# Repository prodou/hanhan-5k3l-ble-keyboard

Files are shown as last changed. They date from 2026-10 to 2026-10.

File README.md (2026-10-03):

# HanHan 5K3L — ESP32-C3 蓝牙五键三灯 + HanHan Agent

## 项目组成

- `firmware/esp32c3_5btn_3led_ble/` — ESP32-C3 固件(Arduino + NimBLE-Arduino)
  - 5 个按键(GPIO0/1/3/4/10)→ BLE HID 键盘, 发送 F13~F17
  - 3 个 LED(GPIO2/6/7, 共用一颗限流电阻)→ 独立的自定义 BLE GATT 特征值控制,
    支持常亮/闪烁/流水灯几种效果模式(见下方"LED 效果协议"), 硬件层固定
    10ms 一帧的分时复用, 三颗灯各自分到一段首尾相接、互不重叠的专属导通窗口,
    **任意时刻最多只有一颗 LED 导通**, 避免共用限流电阻叠加电流; 每颗灯的窗口
    宽度(= 相对亮度)可以自由分配, 只要三者总和不超过 100%(固件会自动按比例
    缩小超出的部分)
  - 启用 BLE 绑定(bonding), 支持断开自动重连; 同时支持**两条并发 BLE 连接**
    (例如手机/电脑当 HID 键盘用的同时, HanHan Agent 再单独连一条做 LED 控制),
    并带有广播看门狗兜底, 避免意外情况下"怎么都搜不到设备"
  - **同时长按 GPIO0 + GPIO1 五秒** → 断开当前连接并清空所有绑定记录, 方便换设备配对
- `HanHanAgent/` — macOS 菜单栏小工具(Swift)
  - 全局拦截来自本设备的 F13~F17 按键(不会传到当前聚焦的窗口)
  - 背景转发(不切换焦点)到用户在菜单里选定的目标 App(固定某个实例, 或"跟随前台窗口"全局模式)
  - 菜单里的"LED 控制..."打开一个独立窗口, 合并了效果预设(全灭/常亮/闪烁/流水灯等)
    和亮度/分配滑块(三个拖动条, 总和 100 以内自由分配), 自动持久化到本地
    并在每次重连时自动下发给固件
- `tools/led_test.py` — 独立的 LED 效果测试脚本(需要 `pip install bleak`,
  且运行环境要有正常的图形登录会话以便弹出蓝牙权限提示)

## LED 效果协议

自定义 Service UUID: `6E400100-...`, 下属两个 Characteristic:

### 效果特征值 `6E400101-...`(mask + mode, 2 字节)

| byte0 (mask) | byte1 (mode) | 效果 |
|---|---|---|
| bit0/1/2 = LED0/1/2 是否参与 | 0 | 全灭(忽略 mask) |
| | 1 | 常亮(mask 选中的灯常亮, `0b111` = 三灯都亮) |
| | 2 | 闪烁(mask 选中的灯一起慢闪: 亮400ms/灭400ms) |
| | 3 | 流水灯(忽略 mask, LED0→LED1→LED2 依次点亮, 每步150ms) |

只写 1 个字节时视为旧协议, 自动当作 `mode=1`(常亮)处理。

### 亮度/分配特征值 `6E400102-...`(3 字节, 可写可读)

`byte[i]` = LED`i` 分配到的"帧内占比"百分比(0~100), **三者总和不能超过 100**
(固件和 HanHan Agent 都会在超出时按比例整体缩小)。时分复用保证任意时刻
最多一颗 LED 导通, 所以无论怎么分配都不会叠加电流, 可以放心按喜好调整:
想让某颗更亮就多分配一些给它, 或者单独调低偏亮的那颗颜色来找平衡。
默认各 30(总和 90)。HanHan Agent 会把每次调整后的值持久化并在每次重连成功后
自动重新下发一遍(固件重启后这个状态会丢失, 需要重新下发)。

> **⚠️ 踩坑记录**: 固件每次新增/修改 BLE 特征值(Characteristic)后, macOS 可能会
> 沿用之前连接缓存的旧 GATT 服务列表, 导致 App 发现不到新加的特征值(表现为:
> App 显示"已连接", 但写入新特征值毫无效果)。解决方法: 系统设置 -> 蓝牙 里把
> "HanHan 5K3L v0.1" 这个设备**移除/忽略**掉, 完全退出并重新打开 HanHan Agent
> 让它重新扫描连接一次, 缓存就会刷新。以后固件 GATT 结构有变化时都建议先这么做一遍。

测试示例:

```bash
pip install bleak
python3 tools/led_test.py static 0b111   # 三灯都亮
python3 tools/led_test.py blink 0b011    # LED0/LED1 一起慢闪
python3 tools/led_test.py chase          # 流水灯
python3 tools/led_test.py off            # 全灭
```

## 固件编译/烧录

需要先安装 `arduino-cli`、ESP32 开发板支持包(`esp32:esp32`)、`NimBLE-Arduino` 库。

```bash
arduino-cli compile --fqbn esp32:esp32:esp32c3:CDCOnBoot=cdc \
  firmware/esp32c3_5btn_3led_ble --output-dir build_out

arduino-cli upload -p /dev/cu.usbmodemXXXX \
  --fqbn esp32:esp32:esp32c3:CDCOnBoot=cdc \
  -i build_out/esp32c3_5btn_3led_ble.ino.bin \
  firmware/esp32c3_5btn_3led_ble
```

烧录前需要先按住 BOOT、再按一下 RESET、再松开 BOOT 进入下载模式
(部分板子插上 USB 会自动进入, 视板子而定)。

## HanHan Agent 安装 / 使用

1. 到 [Releases](../../releases) 下载最新的 `HanHanAgent.zip`, 解压后得到 `HanHan Agent.app`。
2. 拖到 `~/Applications` 或 `/Applications`, 双击打开(首次因为是临时签名, 需要右键 →
   打开 → 确认允许运行)。
3. 打开后会在菜单栏出现 "HH" 图标。第一次运行会请求"辅助功能"权限 ——
   去 **系统设置 → 隐私与安全性 → 辅助功能**, 勾选 "HanHan Agent"
   (没有这个权限完全收不到按键)。
4. 点菜单栏 "HH" 图标, 下拉列表会显示当前运行中的 App, 选择你要接收按键的目标。
5. 按板子上的按键, F13~F17 会被拦截并"背景注入"到选定的目标 App, 不会影响你当前正在
   操作的窗口。

也可以自己从源码编译:

```bash
cd HanHanAgent
./build.sh
open "build/HanHan Agent.app"
```

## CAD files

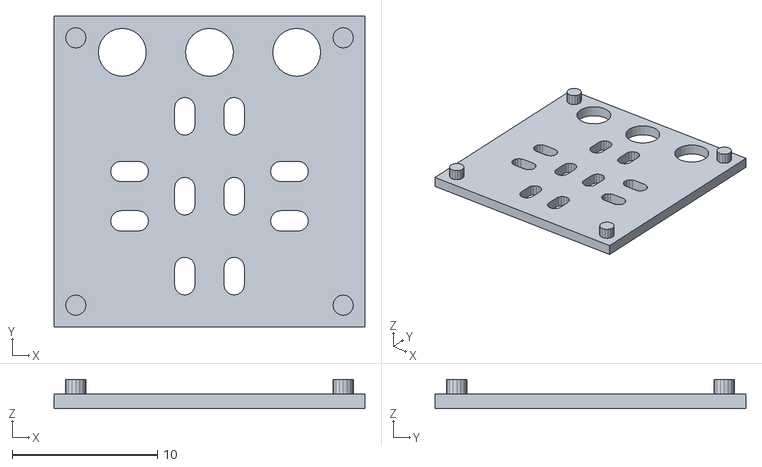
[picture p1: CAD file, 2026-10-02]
dpad_case/retainer.stl
21.4 x 21.4 x 2.00

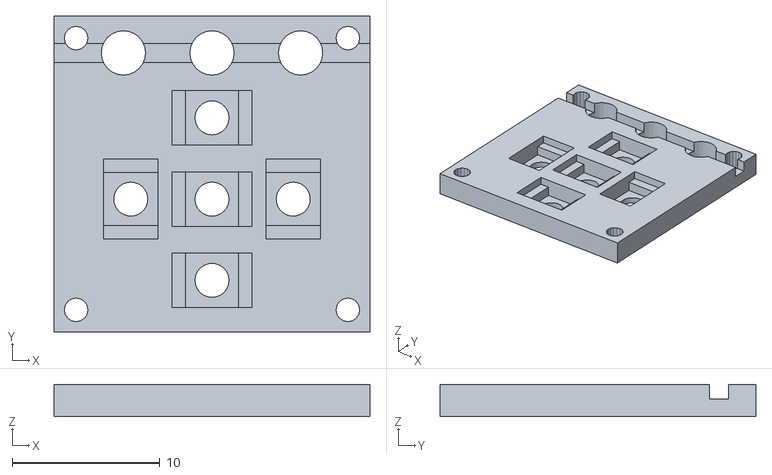
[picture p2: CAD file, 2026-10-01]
dpad_case/carrier.stl
21.4 x 21.4 x 2.20

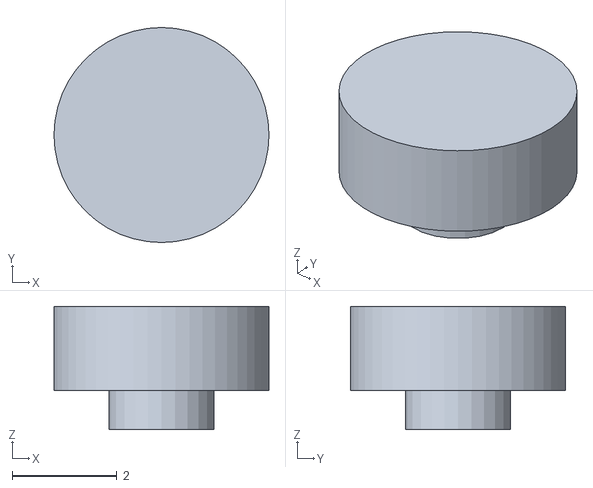
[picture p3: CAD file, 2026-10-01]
dpad_case/cap.stl
4.10 x 4.10 x 2.35

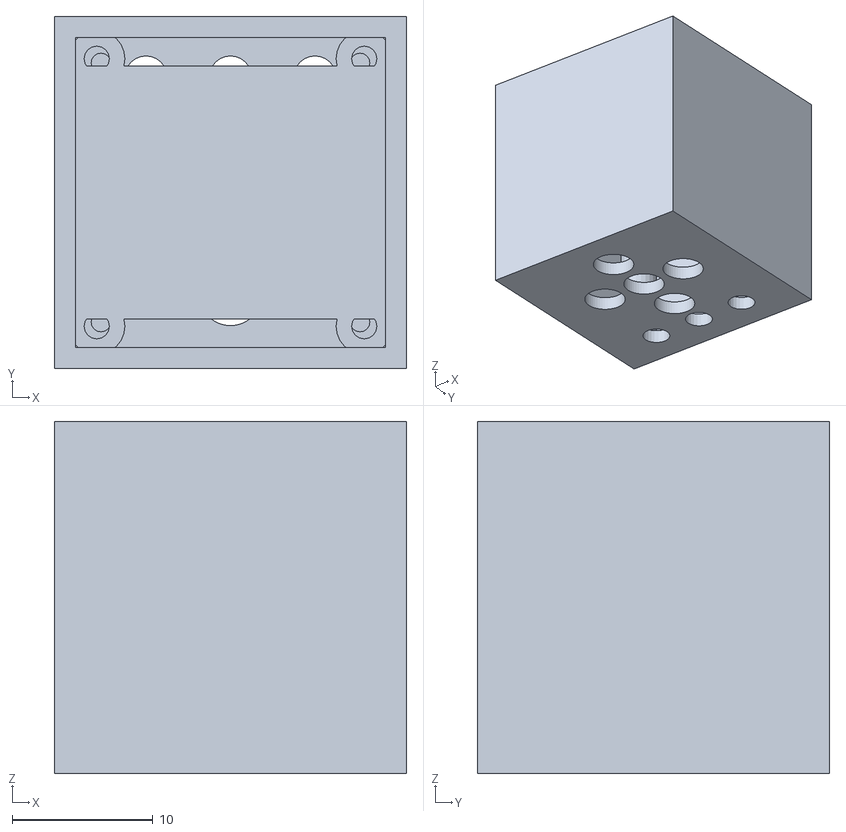
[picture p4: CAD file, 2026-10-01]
dpad_case/shell.stl
25.0 x 25.0 x 25.0

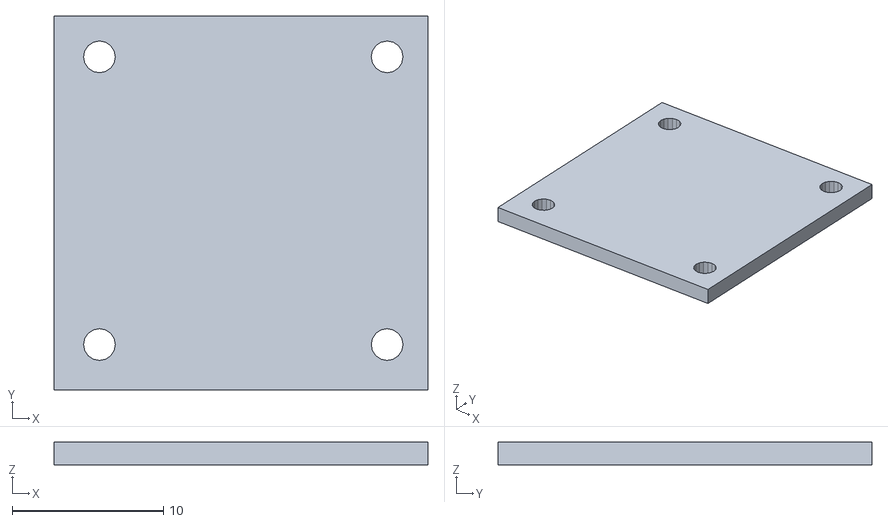
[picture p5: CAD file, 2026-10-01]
dpad_case/back.stl
24.7 x 24.7 x 1.50

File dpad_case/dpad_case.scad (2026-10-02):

// ============================================================
// HanHan 5K3L — 25mm立方体 外壳 + 载板 参数化设计 (v7: 简化卡槽为贯穿式, 走线全部挪到盖板)
// 对应 firmware/esp32c3_5btn_3led_ble
//   5键: GPIO0/1/3/4/10 (上下左右+中)
//   3灯: GPIO2/6/7 (共用限流电阻, 分时复用)
//
// v2改动: 十字按键放大占满22x22; 新增cap零件(面板大孔+小顶杆压实际按键); LED放到十字间隙里
// v3改动: LED改回一排放在面板顶部; cap/面板孔缩小, 露出LED光线; 十字整体下移腾出LED排空间
// v4改动: 根据实拍datasheet量到的真实贴片按键尺寸(3.3x3.4x1.5mm本体,
//   引脚左右伸出共4.0mm, 2mm按压圆点), 重做载板卡槽
// v5改动: 左右按键转90度(引脚变竖直), 同排三键从"引脚对引脚"变"本体对本体",
//   腾出空间加大焊接预留; 每按键独立卡槽+两个过线孔
// v6改动: 卡槽改成"台阶+深槽"结构试图解决引脚比本体低的问题, 新增盖板(retainer)
//   —— 打样后发现引脚两侧那两个深槽做得太大太夸张, 偏离了"中间凹一点放进去"的本意
// v7改动: 卡槽改成简单矩形直接贯穿整个载板厚度 —— 打样后发现贯穿孔从正面
//   看也是两个方正的洞, 偏离了"中间凹一点放按键壳体"的本意, 废弃。
// v8改动(本次, 按反馈再修正): 卡槽改成"从背面往里凹的分层沉孔", 不再贯穿:
//   - 引脚层(leg_zone, 靠背面, 宽=含引脚+焊接预留, 深leg_zone_depth): 放引脚/
//     焊点/引线弯折, 这一层背面是敞开的(不盖东西), 走线从这里直接出去
//   - 本体层(body_zone, 紧接引脚层往正面方向, 窄=贴合按键壳体, 深body_zone_depth):
//     卡住按键本体, 正面看过去只会看到这一层(窄的), 不是方正大洞
//   - 只有对准2mm圆顶的位置, 有个小圆孔(actuator_d)贯穿剩余厚度到正面,
//     让cap的顶杆穿过去压圆顶
//   盖板(retainer)不再开过线孔, 而是在对应每个按键的引脚层位置整块镂空(不盖住),
//   让载板上本来就敞开的引脚层保持敞开, 走线可以直接从背面任意方向出去。
// v9改动(本次): 盖板的镂空改回小孔 —— v8整块镂空开口太大了, 改成只在
//   引脚/引线实际露出的两端各开一个小孔(retainer_hole_d=1.4mm), 其余地方
//   盖板正常贴住载板背面, 把按键稳稳挡住不会往后掉。
//
// 用法:
//   1. 用 OpenSCAD (https://openscad.org) 打开本文件
//   2. 实测你买的贴片按键尺寸/厚度, 改 key_pocket_w / key_pocket_h / actuator_d
//      实测 ESP32-C3-Super-Mini 外形, 改 esp32_w/esp32_l/esp32_t
//      实测 面板到载板到按键顶部的装配间隙, 改 nub_h (这个最关键, 决定手感)
//   3. 顶部 part_to_render 切换要导出的零件, 然后 File > Export > STL
//      cap只需导出一次, 实际打印时在切片软件里阵列复制5个
//
// 建议打印方式: 树脂(SLA/DLP), 孔位/间距在2-7mm级别, FDM精度/公差不够。
// ============================================================

// ====可调参数====
cube_size      = 25;     // 立方体外形边长
wall           = 1.5;    // 外壳壁厚
panel_t        = wall;   // 前面板厚度(与外壳一体打印时=wall)
panel_area     = cube_size - 2*wall; // 面板内侧可用区域(=22, 四壁各留wall厚)

// 按键区(十字布局, 缩小一点, 给顶部LED一排腾出空间)
key_cap_d      = 4.1;    // 面板外露"按键帽"直径(手指按压目标, 比v2缩小)
key_hole_d     = 4.5;    // 面板按键过孔直径(配合cap, 留0.4mm装配间隙)
key_pitch      = 5.5;    // 十字按键中心间距
key_cross_cy   = -1.7;   // 十字整体向下偏移(相对面板中心), 给顶部LED一排留空间

// 实际贴片按键尺寸(来自实拍图实测: 3*3*1.5, 4脚左右两边伸出共4.0mm, 按压圆点约2mm)
button_body_x  = 3.3;    // 本体宽度(不含引脚, 引脚伸出方向)
button_leg_x   = 4.0;    // 含引脚方向的总跨度(引脚两边各伸出0.35mm)
button_body_y  = 3.4;    // 本体宽度(垂直引脚方向)
button_h       = 1.5;    // 按键总高度(贴装面到静止顶部)
button_dome_d  = 2.0;    // 按压圆点直径
actuator_d     = 2.3;    // 载板上贯穿孔径(对准2mm圆点, 留0.3mm余量), cap顶杆由此穿过去压键

// v8改动: 卡槽改成"背面往里凹的分层沉孔", 不贯穿(只有中间圆顶孔贯穿正面)
perp_margin    = 0.15;   // 窄边(垂直引脚方向)预留: 两层都缩到刚好能放进去
leg_margin     = 0.7;    // 引脚方向焊接预留空间(超出引脚尖端, 单边), 留大一点方便焊接不短路
body_margin    = 0.15;   // 本体层沿引脚方向的贴合间隙(单边)
pocket_len     = button_leg_x + 2*leg_margin;   // 引脚层长度(含焊接预留, 沿引脚方向)
pocket_w       = button_body_y + 2*perp_margin; // 两层共用的宽度(垂直引脚方向, 贴合本体)
body_pocket_len = button_body_x + 2*body_margin; // 本体层长度(沿引脚方向, 贴合壳体)
leg_zone_depth  = 0.7;   // 引脚层深度(从背面往里凹, 容纳引脚+焊点+引线弯折高度)
body_zone_depth = 0.9;   // 本体层深度(紧接引脚层, 卡住按键本体, 深度之和约等于按键总高)

wire_groove_w  = 1.3;    // LED引脚走线槽宽(配合0.9mm硅胶线)
wire_groove_depth = 1.0; // 走线槽深度(比按键卡槽浅, 只需过线)

// 按键帽(cap, 单独打印, 装进面板孔里, 背面顶杆对准载板下面的实际按键)
cap_t          = 1.6;    // cap本体厚度(含帽檐)
cap_rim_d      = key_hole_d - 0.4;  // cap外径(略小于面板孔, 留滑动间隙)
nub_d          = 2.0;    // cap背面顶杆直径(对准2mm圆点, 比actuator_d略小可自由穿过)
nub_h          = 0.75;   // cap背面顶杆长度: 需要穿过载板正面那段"只剩圆孔"的通道
                          // = carrier_t - leg_zone_depth - body_zone_depth + 一点预压量
                          // 理论值≈0.6mm通道+0.15预压, 装配后太松/太紧都需要实测微调重新打印!

// LED: 放回顶部一排(cap缩小后腾出的空间), 孔不用太大, 能看到光点就行
led_hole_d     = 3.0;    // 面板LED过孔
led_pitch      = 6.0;    // 三颗LED间距
led_row_cy     = 8.2;    // LED排相对面板中心的y偏移(正值=靠上)
led_positions  = [[-led_pitch,led_row_cy], [0,led_row_cy], [led_pitch,led_row_cy]];

// 载板(carrier plate, 单独打印, 贴在面板内侧)
carrier_w      = panel_area - 0.6;  // 载板宽(比面板可用区域小0.6mm装配间隙)
carrier_h      = panel_area - 0.6;  // 载板高
carrier_t      = 2.2;    // 载板厚度(分层沉孔: 引脚层0.7+本体层0.9, 剩下的0.6留给正面圆孔通道)
carrier_peg_d  = 1.6;    // 载板定位柱直径(对应外壳内侧定位孔)

// 盖板(retainer, 新增第5个零件): 贴在载板背面(靠电池那一侧), 把按键夹在
// 载板和盖板之间防止移动/被顶出来; 对应每个按键的引脚层位置整块镂空(不盖住),
// 让载板本来就敞开的引脚层保持敞开, 走线可以直接从背面出去, 不需要额外开孔。
retainer_t       = 1.0;   // 盖板厚度
retainer_slot_w  = 1.4;   // 盖板过线长条孔的短边宽度(沿引脚方向)
retainer_slot_len= 2.6;   // 盖板过线长条孔的长边长度(沿垂直引脚方向, 一次性盖住两条引脚/引线)
retainer_led_d   = led_hole_d + 0.3; // 盖板上LED过孔径(比面板LED孔略大留装配间隙)
retainer_peg_d   = carrier_peg_d - 0.2; // 盖板定位柱直径(插入载板定位孔背面那一截)
retainer_peg_h   = 1.0;   // 盖板定位柱长度(载板定位孔总深carrier_t=2.2, 正面已被shell的peg占了1.0mm, 背面还剩1.2mm可插)
wire_slot_w    = 3;      // 载板边缘走线缺口宽度(5键+3灯共8根线从此出)
wire_slot_h    = 2;

// 外壳内部: ESP32-C3-Super-Mini 实际尺寸(务必实测修改!)
esp32_w        = 18.0;
esp32_l        = 22.5;
esp32_t        = 4.0;    // 含USB-C插座/天线最高点
usb_slot_w     = 9.5;    // USB-C开口宽(留根据板子USB口位置修改X/Z偏移)
usb_slot_h     = 3.6;

// 后盖螺丝柱
screw_hole_d   = 1.8;    // 自攻螺丝过孔(配M2自攻螺丝)
boss_d         = 4.0;

// ====选择要渲染/导出的零件====
// "shell"     外壳主体(含前面板按键/LED孔+USB开口+内部支柱)
// "carrier"   载板(贴面板内侧, 卡住贴片按键)
// "retainer"  盖板(贴载板背面, 夹住按键防止移动, 打印1个)
// "back"      后盖
// "cap"       按键帽(打印1个, 切片软件里阵列复制5个)
// "assembly"  装配预览(半透明, 仅肉眼检查对齐, 不要用它导出STL)
part_to_render = "shell";

// ============================================================
module key_cross_positions(cx, cy) {
    // 十字: 上下左右 + 中心, 返回5个位置, 正中心对齐(cx,cy), 不再偏移
    positions = [
        [cx, cy + key_pitch],   // 上
        [cx, cy - key_pitch],   // 下
        [cx - key_pitch, cy],   // 左
        [cx + key_pitch, cy],   // 右
        [cx, cy]                // 中
    ];
    for (p = positions) translate(p) children();
}

module led_dots(cx, cy) {
    for (p = led_positions) translate([cx + p[0], cy + p[1]]) children();
}

// ---------------- 外壳主体 ----------------
module shell() {
    difference() {
        cube([cube_size, cube_size, cube_size]);

        // 内部挖空(前面板和四周留wall厚, 后面开口装后盖)
        translate([wall, wall, panel_t])
            cube([cube_size-2*wall, cube_size-2*wall, cube_size]);

        // 前面板按键过孔(放大, 占满panel_area, 居中对齐面板几何中心)
        key_cross_positions(cube_size/2, cube_size/2 + key_cross_cy)
            translate([0,0,-1]) cylinder(d=key_hole_d, h=panel_t+2, $fn=48);

        // LED过孔(十字间隙里)
        led_dots(cube_size/2, cube_size/2)
            translate([0,0,-1]) cylinder(d=led_hole_d, h=panel_t+2, $fn=24);

        // 侧面USB-C开口(假设开在x=0这一侧墙, 靠后部, 按实际ESP32位置调整y/z)
        translate([-1, (cube_size-usb_slot_w)/2, cube_size-esp32_t-3])
            cube([wall+2, usb_slot_w, usb_slot_h]);
    }

    // 内部载板定位柱(4个角, 对应carrier_peg_d孔, 贴着前面板内侧)
    // 注意: carrier()以自身左下角为原点, 实际贴装时需 translate 到
    // (cube_size/2-carrier_w/2, cube_size/2-carrier_h/2, panel_t)
    // 这样carrier本地的按键/LED孔才会和下面shell挖的孔完全对齐
    peg_h = 1.0;
    for (dx = [-1,1]) for (dy = [-1,1])
        translate([cube_size/2 + dx*(carrier_w/2-1.5),
                    cube_size/2 + dy*(carrier_h/2-1.5),
                    panel_t])
            cylinder(d=carrier_peg_d-0.2, h=peg_h, $fn=16);

    // 后盖螺丝柱(四角, 内壁上)
    for (dx = [1,-1]) for (dy=[1,-1])
        translate([cube_size/2 + dx*(cube_size/2-3),
                    cube_size/2 + dy*(cube_size/2-3),
                    panel_t])
            difference(){
                cylinder(d=boss_d, h=cube_size-panel_t-wall, $fn=24);
                translate([0,0,-1]) cylinder(d=screw_hole_d, h=cube_size, $fn=16);
            }

    // ESP32支撑台阶(简单的两条导轨, 贴近后部, 具体位置按板子定)
    translate([wall, cube_size/2-esp32_w/2, cube_size-wall-1])
        cube([cube_size-2*wall, esp32_w, 1]);
}

// 单个按键的卡槽: 从背面(z=carrier_t这一侧)往里凹的分层沉孔, 不贯穿到正面
// (vertical=false: 引脚水平/沿x方向; true: 引脚转90度/沿y方向)
//   - 引脚层: 靠背面, 宽(含引脚+焊接预留), 深leg_zone_depth, 背面敞开走线
//   - 本体层: 紧接引脚层往正面方向, 窄(贴合本体), 深body_zone_depth
//   - 圆顶通孔: 从本体层继续贯穿剩余厚度到正面, 让cap顶杆穿过去压圆顶
module key_pocket(cx, cy, vertical) {
    eps = 0.05;

    leg_px = vertical ? pocket_w : pocket_len;
    leg_py = vertical ? pocket_len : pocket_w;
    translate([cx-leg_px/2, cy-leg_py/2, carrier_t-leg_zone_depth-eps])
        cube([leg_px, leg_py, leg_zone_depth+eps]);

    body_px = vertical ? pocket_w : body_pocket_len;
    body_py = vertical ? body_pocket_len : pocket_w;
    translate([cx-body_px/2, cy-body_py/2, carrier_t-leg_zone_depth-body_zone_depth-eps])
        cube([body_px, body_py, body_zone_depth+2*eps]);

    translate([cx, cy, -0.5])
        cylinder(d=actuator_d, h=carrier_t-leg_zone_depth-body_zone_depth+0.5+eps, $fn=32);
}

// ---------------- 载板(贴片按键固定件) ----------------
// 5个按键各自独立开卡槽(背面分层沉孔, 只有中间圆顶孔贯穿正面), 上/下/中 三键
// 引脚保持水平(H), 左/右 两键转90度变成引脚竖直(V) —— 这样同一排的左/中/右
// 三键之间就不再是"引脚对引脚"占满4.0mm宽度, 而是"本体对本体"只占3.4mm宽度,
// 省出来的空间正好用来加大 leg_margin, 让焊接/走线更宽松不容易短路。
module carrier() {
    cx = carrier_w/2;
    cy = carrier_h/2 + key_cross_cy;
    difference() {
        cube([carrier_w, carrier_h, carrier_t]);
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

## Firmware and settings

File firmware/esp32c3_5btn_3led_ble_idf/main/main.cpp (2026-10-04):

#include "Arduino.h"
#include "esp_pm.h"
#include "esp_sleep.h"
#include "driver/ledc.h"
#include "driver/gpio.h"
#include "freertos/FreeRTOS.h"
#include "freertos/task.h"

// 关键修复: 我们用的是 esp-nimble-cpp (非 Arduino 自带的 BLE 库),
// 所以 Arduino 核心里跟踪 "BLE 是否被使用" 的 _bleLibraryInUse 标志永远不会
// 被设置为 true (它只在链接 Arduino 自带 BLE 库时才会被置位)。
// initArduino() 据此误判 BLE 未被使用, 在 setup() 之前就调用了
// btMemRelease(BT_MODE_BLE) 把 BLE 控制器内存释放掉了, 导致随后
// NimBLEDevice::init() 在已释放的内存上初始化控制器, 出现两次
// "MAGIC fadebead" 初始化尝试、HLI Magic mismatch、最终空指针崩溃。
// 这里提供一个强符号覆盖掉 esp32-hal-bt.c 里的 weak bleInUse(),
// 告诉 Arduino 核心: BLE 确实在用, 不要释放这块内存。
extern "C" bool bleInUse(void) {
  return true;
}
/*
  ESP32-C3 五键三灯 BLE HID 方案
  --------------------------------
  重要硬件说明:
    ESP32-C3 只有 "USB Serial/JTAG" 控制器, 不支持真正的 USB-OTG/HID,
    所以本方案改为 **BLE(蓝牙低功耗)HID 键盘**, USB-C 仅用于供电和烧录/
    串口调试, 不参与按键/LED 功能。

  硬件连接:
    - 按键(内部上拉,按下=低电平): GPIO0, GPIO1, GPIO3, GPIO5, GPIO10 -> 另一端接 GND
      (GPIO0 是下载/BOOT 选通脚, 只要不是在"复位瞬间"被按住就不影响正常运行;
       原方案 F16 按键在 GPIO4, 现挪到 GPIO5, 把 GPIO4 让给电池 ADC 检测,
       因为 ESP32-C3 的 ADC2/GPIO5 实际不可用, 只有 ADC1/GPIO0~4 能读电压)
    - LED(共用同一限流电阻到 GND, 需分时点亮避免叠加电流):
        LED0 = GPIO2, LED1 = GPIO6, LED2 = GPIO7
    - 电池电压检测: GPIO4(ADC1) <- 两颗 220k/220k 等值分压电阻的中点,
      单节锂电池正极(最高 4.2V)经过 1:2 分压后约 0~2.1V 落在 ADC 安全量程内,
      固件内部再乘 2 还原成实际电池电压

  功能:
    1. 按键按下/松开 -> 通过标准 BLE HID 键盘 Input Report 发送 F13~F17,
       电脑蓝牙配对后当普通蓝牙键盘识别,主机侧用监听/映射软件识别这几个键。
    2. 3 个 LED 是"自定义功能指示灯",与系统的大小写/数字/滚动锁无关,
       所以**不使用**标准 HID 键盘 LED 输出报文(会被系统/其它键盘联动误触发),
       改用一个独立的**自定义 BLE GATT 特征值**(单独 Service/Characteristic),
       电脑端程序连接 BLE 后直接写这个特征值 2 个字节:
         byte0 = mask, bit0/1/2 分别对应 LED0(GPIO2)/LED1(GPIO6)/LED2(GPIO7) 是否参与显示
         byte1 = mode, 效果模式:
           0 = 全灭(忽略 mask)
           1 = 常亮  (mask 选中的灯常亮显示, 例: mask=0b111 即"三灯都亮")
           2 = 闪烁  (mask 选中的灯整体慢闪: 亮400ms / 灭400ms)
           3 = 流水灯(忽略 mask, LED0->LED1->LED2->LED0 顺序点亮, 每步150ms)
         只发 1 个字节时视为旧协议, 自动当作 byte1=1(常亮) 处理, 保持向后兼容。
       另有一个**亮度/带宽分配特征值**(同 Service 下), 写 3 个字节:
         byte0/1/2 = LED0/1/2 分配到的"帧内占比"百分比(0~100),
         **三者总和不能超过 100**(固件会按比例整体缩小超出的部分), 默认各 30。
         可以用来抵消不同颜色 LED 正向压降不同导致的肉眼亮度不一致,
         也可以在总预算内自由分配(比如某颗想格外亮一些就多分配给它)。
    3. **任意时刻三颗 LED 最多只有一颗导通, 不会在共用限流电阻上叠加电流**:
       硬件上 3 颗 LED 共用同一限流电阻到 GND, 为避免叠加电流,
       采用 10ms 为一帧的分时复用, 三颗灯各自分到一段首尾相接、互不重叠的
       专属导通窗口, 窗口宽度 = 10ms * 分配百分比/100(微秒级精度):
         LED0 窗口: [0, w0)
         LED1 窗口: [w0, w0+w1)
         LED2 窗口: [w0+w1, w0+w1+w2)
         (剩余部分, 如果 w0+w1+w2 < 10ms) : 全灭(帧尾间隔)
       "常亮"/"闪烁"/"流水灯"等上层效果只决定某颗 LED 在当前宏观时刻
       是否参与这个分时复用(即是否允许在轮到它的窗口导通),
       从不会让任何一颗 LED 跳过分时直接常通, 从根本上保证任意时刻
       最多同时一颗导通, 电气上绝对安全; 分配比例只影响"相对亮度",
       不影响"互斥性"这个安全保证。
    4. 支持**同时**连接手机/电脑(HID 键盘)和 HanHan Agent(LED 控制)两条独立
       BLE 连接: 每次有新连接建立后, 只要当前连接数还没到上限(2), 就会自动
       重新开启广播以便接纳另一条连接; loop() 里也有兜底逻辑, 只要连接数未满
       且当前没有在广播, 就会定期自动重新开启广播, 避免因为某次异常导致
       广播停掉后再也连不上。
    5. 电池电压检测与上报: 每 10 秒读一次 GPIO5 的 ADC 电压(多次采样取平均降噪),
       乘以分压比(x2)还原成实际电池电压, 再按单节锂电池 4.2V(满)~3.0V(空)
       的放电曲线换算成百分比, 通过两种方式上报:
         a) 标准 BLE 电池服务(0x180F, Battery Level 特征值 0x2A19) —— 只报百分比,
            系统/手机蓝牙设置里会原生显示电池图标, 这是 NimBLEHIDDevice 自带的。
         b) 自定义电压特征值(同 LED Service 下, UUID 见下方) —— 报 3 字节:
            byte0/1 = 电压毫伏(uint16, 小端), byte2 = 百分比(0~100),
            支持 Notify, 供 HanHan Agent 显示具体电压数值。

  Arduino IDE 设置:
    开发板:  ESP32C3 Dev Module
    需要先安装库: NimBLE-Arduino (Library Manager 搜索安装)
    其余选项保持默认即可(不需要 USB CDC/USB OTG 相关设置)
*/

#include <NimBLEDevice.h>
#include <NimBLEServer.h>
#include <NimBLEHIDDevice.h>
#include <HIDTypes.h>

// ------------------- BLE HID 键盘 报文描述符 (仅 Keyboard, Report ID = 1) -------------------
#define KEYBOARD_ID 0x01
static const uint8_t hidReportDescriptor[] = {
  USAGE_PAGE(1),      0x01,        // USAGE_PAGE (Generic Desktop Ctrls)
  USAGE(1),           0x06,        // USAGE (Keyboard)
  COLLECTION(1),      0x01,        // COLLECTION (Application)
  REPORT_ID(1),       KEYBOARD_ID, //   REPORT_ID (1)
  USAGE_PAGE(1),      0x07,        //   USAGE_PAGE (Kbrd/Keypad)
  USAGE_MINIMUM(1),   0xE0,        //   USAGE_MINIMUM (0xE0)
  USAGE_MAXIMUM(1),   0xE7,        //   USAGE_MAXIMUM (0xE7)
  LOGICAL_MINIMUM(1), 0x00,        //   LOGICAL_MINIMUM (0)
  LOGICAL_MAXIMUM(1), 0x01,        //   LOGICAL_MAXIMUM (1)
  REPORT_SIZE(1),     0x01,        //   REPORT_SIZE (1)
  REPORT_COUNT(1),    0x08,        //   REPORT_COUNT (8)   -> 8 个修饰键 bit
  HIDINPUT(1),        0x02,        //   INPUT (Data,Var,Abs)
  REPORT_COUNT(1),    0x01,        //   REPORT_COUNT (1)   -> 1 字节保留
  REPORT_SIZE(1),     0x08,        //   REPORT_SIZE (8)
  HIDINPUT(1),        0x01,        //   INPUT (Const,Array,Abs)
  REPORT_COUNT(1),    0x06,        //   REPORT_COUNT (6)   -> 6 字节按键码
  REPORT_SIZE(1),     0x08,        //   REPORT_SIZE (8)
  LOGICAL_MINIMUM(1), 0x00,
  LOGICAL_MAXIMUM(1), 0x65,
  USAGE_PAGE(1),      0x07,
  USAGE_MINIMUM(1),   0x00,
  USAGE_MAXIMUM(1),   0x65,
  HIDINPUT(1),        0x00,        //   INPUT (Data,Array,Abs)
  END_COLLECTION(0)
};

// 按键在 USB/BLE HID Keyboard Usage Page 上的标准键码: F13~F17
// (选用这几个键是因为几乎不会被系统/其他软件占用, 方便 HanHan Agent 安全拦截转发)
static const uint8_t KEY_F13 = 0x68;
static const uint8_t KEY_F14 = 0x69;
static const uint8_t KEY_F15 = 0x6A;
static const uint8_t KEY_F16 = 0x6B;
static const uint8_t KEY_F17 = 0x6C;

NimBLEServer *pServer = nullptr;
NimBLEHIDDevice *pHid = nullptr;
NimBLECharacteristic *pInputKeyboard = nullptr;
NimBLECharacteristic *pLedStatusChr = nullptr;

volatile bool bleConnected = false;

// ------------------- 自定义 LED 状态 BLE 服务 -------------------
// 独立于 HID 服务, 使用自定义 128-bit UUID, 与系统键盘锁定状态完全隔离。
#define LED_SERVICE_UUID "6E400100-B5A3-F393-E0A9-E50E24DCCA9E"
#define LED_STATUS_CHAR_UUID "6E400101-B5A3-F393-E0A9-E50E24DCCA9E"
#define LED_CALIB_CHAR_UUID "6E400102-B5A3-F393-E0A9-E50E24DCCA9E"
#define BATTERY_VOLTAGE_CHAR_UUID "6E400103-B5A3-F393-E0A9-E50E24DCCA9E"

// 效果模式: 0=全灭 1=常亮 2=闪烁 3=流水灯
enum LedMode : uint8_t {
  LED_MODE_OFF = 0,
  LED_MODE_STATIC = 1,
  LED_MODE_BLINK = 2,
  LED_MODE_CHASE = 3,
};

const uint8_t LED_ALLOC_SUM_MAX = 100; // 三颗灯的分配百分比总和上限(时分复用天然保证任意时刻只有一颗导通,
                                        // 所以只要总和不超过一帧, 怎么分配都不会叠加电流)

RTC_DATA_ATTR volatile bool ledEnabled[3] = {false, false, false}; // mask: 常亮/闪烁模式下哪些灯参与显示
RTC_DATA_ATTR volatile uint8_t ledMode = LED_MODE_STATIC;
// 每颗 LED 分配到的帧内占比(0~100), 三者总和不能超过 100, 用于:
//   1) 抵消不同颜色 LED 正向压降不同导致的肉眼亮度差异
//   2) 让用户在总预算内自由分配亮度(比如想要某颗更亮, 可以多分配一些给它)
// 默认三等分(各 30, 总和 90, 留一点余量), 由 HanHan Agent 下发调整。
// 注意: 这三个 LED 状态变量标了 RTC_DATA_ATTR, 是为了配合下面的深度睡眠省电方案——
// 深度睡眠会断电重启(只有 RTC 内存域不断电), 加这个属性后这几个变量的值能在
// 深度睡眠醒来后还保留(不会被重新初始化成默认值), 这样电脑之前下发的 LED 状态
// 不会因为芯片睡一觉就丢掉。
RTC_DATA_ATTR volatile uint8_t ledAllocPercent[3] = {30, 30, 30};

// 把三个百分比值按总和 <=100 的约束夹一遍: 单值先夹到 0~100, 总和超了就按比例整体缩小。
void clampLedAllocation(uint8_t vals[3]) {
  uint32_t sum = 0;
  for (uint8_t i = 0; i < 3; i++) {
    if (vals[i] > LED_ALLOC_SUM_MAX) vals[i] = LED_ALLOC_SUM_MAX;
    sum += vals[i];
  }
  if (sum > LED_ALLOC_SUM_MAX && sum > 0) {
    for (uint8_t i = 0; i < 3; i++) {
      vals[i] = (uint8_t)((uint32_t)vals[i] * LED_ALLOC_SUM_MAX / sum);
    }
  }
}

// 省电关键改动: LED 改用硬件 LEDC PWM(见下方 applyLedOutputs()/ledcSetup()),
// 不再需要 CPU 每 1ms 醒来手动翻转 GPIO。这里先声明, 供上面的 BLE 写回调
// (配置一变就立刻应用一次) 和下面的闪烁/流水灯定时步进调用。
void applyLedOutputs();

// ---- 空闲深度睡眠省电 ----
// 长时间没人碰按键时, 让芯片整体进入"深度睡眠"(比目前的 light sleep 更彻底,
// CPU/BLE 控制器全部断电, 只留 RTC 域); 醒来时等同于重新开机, BLE 栈重新初始化
// 广播——这条"断电重插后总能自动重连、不用重新配对"的路径已经在这个项目里
// 反复验证过是可靠的(而直接调用 BLE disconnect() 主动断连, 实测 macOS 不会
// 自动重连, 需要手动忽略设备重新搜索, 行不通, 这里改用深度睡眠绕开这个问题)。
// 代价:
//   1) ESP32-C3 只有 GPIO0/1/3/5 这几个脚支持深度睡眠时的按键唤醒, 接在 GPIO10
//      上的那颗键(回车键)没有这个硬件能力, 单独按它无法唤醒芯片, 要等下面的
//      定时唤醒窗口才会被处理(电脑想点亮 LED 也是靠这个定时窗口推送, 两者延迟
//      量级相同, 都在 DEEP_SLEEP_PERIOD_US 以内)。
//   2) 断开期间电脑要点亮 LED 会有延迟(最多到下一次定时唤醒广播窗口为止)。
//   3) 睡眠期间如果 LED 效果是"2颗或3颗同时亮"(分时复用), 没法在断电期间维持
//      这种动态波形, 会在睡眠期间暂时熄灭、醒来后恢复; 常见的"0~1颗常亮"场景
//      通过下面的 GPIO hold 机制可以在睡眠期间维持物理电平不灭。
// 按键活跃时, 允许连续按键/短暂停顿后继续按键而不必每次都重新走一遍(较贵的)
// BLE 重连; 10 秒给得比较松, 减少"刚断又要连"的来回折腾。
const uint32_t IDLE_SLEEP_MS = 10000;       // 距上次按键 10 秒没有任何按键活动就准备深度睡眠
// 单纯的定时醒来(没人按键、电脑也没连上来)场景下, 不需要陪跑到 IDLE_SLEEP_MS
// 这么久——只要给 BLE 协议栈/广播一点点启动时间即可, 没事就尽快回去睡觉。
const uint32_t MIN_AWAKE_MS = 1500;         // 每次醒来至少保持 1.5 秒, 留时间给 BLE 栈起来广播
// 电脑连上来写一次 LED 指令后, 不必等到 IDLE_SLEEP_MS 那么久——执行完指令、
// 留一点点余量让 ACK/通知发出去就可以尽快回去睡觉了。
const uint32_t BLE_QUICK_SLEEP_MS = 2000;   // 连接/收到一次指令后, 额外多等这么久就可以睡了
const uint64_t DEEP_SLEEP_PERIOD_US = 10000000ULL; // 最长睡 10 秒后定时醒来广播一次(刚好对齐你接受的≤10秒延迟上限)
volatile uint32_t lastActivityMs = 0;  // 最近一次"按键"活动(决定能不能继续用 10 秒长窗口)
volatile uint32_t lastBleEventMs = 0;  // 最近一次"BLE 连接/收到指令"活动(只给短窗口)
uint32_t bootTimeMs = 0; // 本次(深度睡眠醒来后的新一轮)开机时间, 配合 MIN_AWAKE_MS 使用

// 按键活动时在本地立即熄灭所有 LED(不等电脑指令), 让用户按键时能立刻看到反馈;
// 电脑下次想点亮 LED 会重新写入 ledEnabled, 和这里互不冲突。
void onLocalActivity() {
  lastActivityMs = millis();
  if (ledEnabled[0] || ledEnabled[1] || ledEnabled[2]) {
    ledEnabled[0] = false;
    ledEnabled[1] = false;
    ledEnabled[2] = false;
    applyLedOutputs();
  }
}

// 深度睡眠前, 尽量让 LED 物理电平在断电期间也保持住(见上面代价3的说明):
// 只有同时最多 1 颗 LED 要求亮起时才能用 GPIO hold 稳定维持(本来就是最常见的
// 用法——三颗灯分别代表不同状态, 很少同时点亮), 2/3 颗同时亮的分时复用场景
// 没法在睡眠期间维持, 直接放行让它们暂时熄灭。
void prepareLedsForDeepSleep();

class LedStatusCallbacks : public NimBLECharacteristicCallbacks {
  void onWrite(NimBLECharacteristic *pChr, NimBLEConnInfo &connInfo) override {
    std::string v = pChr->getValue();
    if (v.length() == 0) {
      return;
    }
    uint8_t mask = (uint8_t)v[0];
    ledEnabled[0] = mask & 0x01;
    ledEnabled[1] = mask & 0x02;
    ledEnabled[2] = mask & 0x04;
    // 只写 1 字节时视为旧协议, 默认常亮模式, 保持向后兼容
    ledMode = (v.length() >= 2) ? (uint8_t)v[1] : LED_MODE_STATIC;
    Serial.printf("[LED] write mask=0b%03b mode=%u\n", mask & 0x07, ledMode);
    applyLedOutputs();
    lastBleEventMs = millis(); // 指令已执行, 只需再等 BLE_QUICK_SLEEP_MS 就能睡
  }
};

class LedCalibCallbacks : public NimBLECharacteristicCallbacks {
  void onWrite(NimBLECharacteristic *pChr, NimBLEConnInfo &connInfo) override {
    std::string v = pChr->getValue();
    if (v.length() < 3) return;
    uint8_t vals[3] = {(uint8_t)v[0], (uint8_t)v[1], (uint8_t)v[2]};
    clampLedAllocation(vals);
    ledAllocPercent[0] = vals[0];
    ledAllocPercent[1] = vals[1];
    ledAllocPercent[2] = vals[2];
    Serial.printf("[LED] allocation%% = %u, %u, %u\n",
                  ledAllocPercent[0], ledAllocPercent[1], ledAllocPercent[2]);
    applyLedOutputs();
    lastBleEventMs = millis(); // 指令已执行, 只需再等 BLE_QUICK_SLEEP_MS 就能睡
  }
};

NimBLECharacteristic *pLedCalibChr = nullptr;

// ------------------- 电池电压检测 -------------------
// 单节锂电池(满 4.2V / 建议放电下限 3.0V)经过 220k+220k 等值分压后接到 GPIO4(ADC1),
// ADC 读数约为电池电压的一半, 固件内部乘 2 还原。
const uint8_t BATTERY_ADC_PIN = 4; // ESP32-C3 的 ADC2(GPIO5) 实际不可用("adc unit not supported"),
                                    // 只有 ADC1(GPIO0~4) 能用, 所以改用原按键占用的 GPIO4,
                                    // 对应把那颗按键的线挪到 GPIO5(纯数字输入, 不需要 ADC)
const float BATTERY_DIVIDER_RATIO = 2.0f; // 分压比的倒数: 实际电压 = ADC电压 * 2
const uint32_t BATTERY_SAMPLE_COUNT = 16;  // 多次采样取平均, 降低 ADC 噪声
const uint32_t BATTERY_REPORT_INTERVAL_MS = 60000; // 电池电压变化很慢, 10秒测一次没必要,
                                                    // 改成60秒, 减少唤醒+ADC采样次数(省电)

NimBLECharacteristic *pBatteryVoltageChr = nullptr;
uint32_t lastBatteryReportMs = 0;
uint16_t lastBatteryMv = 0;
uint8_t lastBatteryPercent = 0;

// 单节锂电池放电曲线的简单分段线性近似(电压 mV -> 百分比), 比纯线性更贴近真实电量观感。
// 电压越界(超过 4200 或低于 3000)会被夹到 100/0。
uint8_t batteryVoltageToPercent(uint16_t mv) {
  struct Point { uint16_t mv; uint8_t pct; };
  static const Point curve[] = {
    {4200, 100}, {4060, 90}, {3980, 80}, {3920, 70}, {3870, 65},
    {3820, 60},  {3790, 55}, {3770, 50}, {3740, 45}, {3680, 40},
    {3600, 30},  {3450, 20}, {3270, 10}, {3000, 0},
  };
  const int n = sizeof(curve) / sizeof(curve[0]);
  if (mv >= curve[0].mv) return 100;
  if (mv <= curve[n - 1].mv) return 0;
  for (int i = 0; i < n - 1; i++) {
    if (mv <= curve[i].mv && mv >= curve[i + 1].mv) {
      // 在 curve[i+1] ~ curve[i] 之间线性插值
      float t = (float)(mv - curve[i + 1].mv) / (float)(curve[i].mv - curve[i + 1].mv);
      return (uint8_t)(curve[i + 1].pct + t * (curve[i].pct - curve[i + 1].pct));
    }
  }
  return 0;
}

// 读取一次电池电压(多次采样平均), 更新 BLE 特征值并按需 notify, 同时同步到标准电池服务。
void updateBatteryReading() {
  uint32_t sumMv = 0;
  for (uint32_t i = 0; i < BATTERY_SAMPLE_COUNT; i++) {
    sumMv += analogReadMilliVolts(BATTERY_ADC_PIN);
  }
  uint16_t adcMv = (uint16_t)(sumMv / BATTERY_SAMPLE_COUNT);
  uint16_t batteryMv = (uint16_t)(adcMv * BATTERY_DIVIDER_RATIO);
  uint8_t percent = batteryVoltageToPercent(batteryMv);

  lastBatteryMv = batteryMv;
  lastBatteryPercent = percent;

  Serial.printf("[BATTERY] adc=%umV battery=%umV percent=%u%%\n", adcMv, batteryMv, percent);

  if (pBatteryVoltageChr) {
    uint8_t payload[3] = {(uint8_t)(batteryMv & 0xFF), (uint8_t)(batteryMv >> 8), percent};
    pBatteryVoltageChr->setValue(payload, 3);
    if (bleConnected) {
      pBatteryVoltageChr->notify();
    }
  }
  if (pHid) {
    pHid->setBatteryLevel(percent, bleConnected);
  }
}


// 同时允许的最大连接数。原来设成2是以为手机/电脑的HID连接和HanHan Agent的
// LED控制连接是两条独立连接, 需要各占一条。后来证实HanHan Agent优先复用
// 系统已有的那条连接(retrieveConnectedPeripherals), 并不会额外建连接;
// 加上用户确认平时只用一台设备连接, 改成1之后, 连上这一台设备后就彻底
// 停止广播, 省掉广播包本身的周期性射频开销。
const uint8_t MAX_DESIRED_CONNECTIONS = 1;

class ServerCallbacks : public NimBLEServerCallbacks {
  void onConnect(NimBLEServer *server, NimBLEConnInfo &connInfo) override {
    bleConnected = true;
    lastBleEventMs = millis(); // 连接建立也算一次 BLE 活动, 给 BLE_QUICK_SLEEP_MS
                                // 的短窗口, 留时间给电脑把 LED 指令写进来(之前这里
                                // 没刷新, 实测出现连上 1 秒不到又被强制睡眠, 按键
                                // 完全来不及送达电脑的问题)。
    Serial.printf("[BLE] onConnect, connectedCount=%u\n", server->getConnectedCount());
    // 只要还没到连接数上限, 继续广播以便接纳另一条连接(例如手机当键盘用的同时,
    // HanHan Agent 还要单独连一条 BLE 来控制 LED)
    if (server->getConnectedCount() < MAX_DESIRED_CONNECTIONS) {
      NimBLEDevice::startAdvertising();
    }
    // 省电: 主动请求拉长连接间隔 + 增大 slave latency, 减少无线电唤醒次数。
    // 单位: interval=1.25ms 步进, timeout=10ms 步进。
    // min=30ms, max=100ms, latency=10(空闲时最多可跳过10个连接事件不响应,
    // 相当于空闲时实际间隔可放宽到 ~1.1s), timeout=6s。
    // 这是"建议值", 最终由对端(手机/电脑系统蓝牙或 HanHan Agent)决定是否采纳;
    // 如果对端没有完全按这个来, 射频仍会较频繁唤醒, 耗电会更接近"不省电"的水平。
    // 对于偶尔按键的场景, 这点延迟可接受, 换来待机耗电显著下降。
    server->updateConnParams(connInfo.getConnHandle(), 24, 80, 10, 600);
  }
  // 诊断用: 打印对端(手机/电脑系统蓝牙)最终实际采纳的连接参数, 用来确认
  // "对端没有按我们的请求来, 实际间隔仍然很短" 这个猜测是否属实。
  // 注意: 这个事件发生在运行期(不在开机 grace 窗口内), USB-Serial-JTAG
  // 在 light sleep 深睡后会读不到, 如果要抓这条日志, 需要在参数协商刚
  // 完成、设备还没进入深度 light sleep 的那一小段时间内连上串口监听。
  void onConnParamsUpdate(NimBLEConnInfo &connInfo) override {
    Serial.printf("[BLE] connParams updated: interval=%.2fms latency=%u timeout=%ums\n",
                  connInfo.getConnInterval() * 1.25f, connInfo.getConnLatency(),
                  connInfo.getConnTimeout() * 10);
  }
  void onDisconnect(NimBLEServer *server, NimBLEConnInfo &connInfo, int reason) override {
    bleConnected = server->getConnectedCount() > 0;
    Serial.printf("[BLE] onDisconnect reason=%d, connectedCount=%u\n", reason, server->getConnectedCount());
    NimBLEDevice::startAdvertising();
  }
};

// ------------------- 按键配置 -------------------
struct Button {
  uint8_t pin;
  uint8_t keycode;
  bool lastStable;   // 消抖后的稳定电平 (true = 高/未按下)
  bool lastRaw;      // 上一次读到的原始电平
  uint32_t lastChangeMs;
  bool pressedSent;  // 是否已经发送过 press
};

// GPIO0/1/3/5/10 -> F13~F17 (原 GPIO4 已让给电池分压 ADC, 该按键改接到 GPIO5)
Button buttons[5] = {
  {0,  KEY_F13, true, true, 0, false},
  {1,  KEY_F14, true, true, 0, false},
  {3,  KEY_F15, true, true, 0, false},
  {5,  KEY_F16, true, true, 0, false},
  {10, KEY_F17, true, true, 0, false},
};

const uint32_t DEBOUNCE_MS = 20;

// 省电关键改动: 按键不再靠 loop() 每 1ms 轮询 digitalRead(), 改成 GPIO
// 电平变化中断唤醒。中断里只做最轻量的"叫醒主任务"(xTaskNotifyGive),
// 真正的消抖/判断逻辑还是在 scanButtons() 里跑(逻辑不变), 只是触发时机从
// "每 1ms 必定跑一次"变成"有变化或到了消抖截止时间才跑一次", 这样 CPU 在
// 没人按键、LED 不需要更新的时候可以真正进入 light sleep。
TaskHandle_t mainTaskHandle = nullptr;

void IRAM_ATTR buttonIsr() {
  BaseType_t woken = pdFALSE;
  vTaskNotifyGiveFromISR(mainTaskHandle, &woken);
  if (woken) portYIELD_FROM_ISR();
}


// ------------------- 清空绑定组合键(GPIO0 + GPIO1 同时长按 5 秒) -------------------
// 注意: 执行后会主动断开当前连接并清空板子这边保存的全部绑定密钥,
// 此时原来连接的手机/电脑只会看到"普通断开"(不会提示"已解绑"),
// 它自己保存的配对记录并不会被清掉。若之后它尝试自动重连会因为密钥不匹配而连接失败(无提示),
// 需要在对方设备上也手动"忽略此设备/取消配对"后重新扫描配对。
const uint32_t UNBOND_HOLD_MS = 5000;
uint32_t comboHoldStartMs = 0;
bool comboHolding = false;
bool comboTriggered = false;

void handleUnbondCombo() {
  bool pin0Pressed = (digitalRead(0) == LOW);
  bool pin1Pressed = (digitalRead(1) == LOW);
  uint32_t now = millis();

  if (pin0Pressed && pin1Pressed) {
    if (!comboHolding) {
      comboHolding = true;
      comboHoldStartMs = now;
      comboTriggered = false;
    } else if (!comboTriggered && (now - comboHoldStartMs) >= UNBOND_HOLD_MS) {
      comboTriggered = true;
      Serial.println("[BLE] combo held 5s -> disconnect + clear all bonds");
      if (pServer && pServer->getConnectedCount() > 0) {
        for (uint16_t connHandle : pServer->getPeerDevices()) {
          pServer->disconnect(connHandle);
        }
      }
      NimBLEDevice::deleteAllBonds();
      NimBLEDevice::startAdvertising();
    }
  } else {
    comboHolding = false;
    comboTriggered = false;
  }
}

// 空闲太久(IDLE_SLEEP_MS 内没有任何按键活动, 且至少已经醒了 MIN_AWAKE_MS)时
// 进入深度睡眠; GPIO0/1/3/5 按键 + 定时器会把它重新唤醒(见上面 IDLE_SLEEP_MS
// 注释), 醒来后相当于重新开机, setup() 里会重新初始化 BLE 并开始广播。
// 空闲太久时进入深度睡眠, 分两种情况判断(见上面常量注释):
//   - 有按键活动: 按 IDLE_SLEEP_MS(10秒) 的长窗口等, 方便连续按键。
//   - 只有 BLE 连接/指令、没有按键: 按 BLE_QUICK_SLEEP_MS(2秒) 的短窗口等,
//     指令执行完/没人连接就尽快回去睡觉, 不陪跑没必要的长时间。
// GPIO0/1/3/5 按键 + 定时器会把它重新唤醒(见上面 IDLE_SLEEP_MS 注释), 醒来后
// 相当于重新开机, setup() 里会重新初始化 BLE 并开始广播。
void goToDeepSleepIfIdle() {
  uint32_t now = millis();
  if ((int32_t)(now - bootTimeMs) < (int32_t)MIN_AWAKE_MS) return; // 刚醒不久, 先留时间给 BLE
  if ((int32_t)(now - lastActivityMs) < (int32_t)IDLE_SLEEP_MS) return;      // 按键长窗口还没到
  if ((int32_t)(now - lastBleEventMs) < (int32_t)BLE_QUICK_SLEEP_MS) return; // BLE 短窗口还没到

  Serial.println("[SLEEP] idle -> entering deep sleep");
  Serial.flush();

  prepareLedsForDeepSleep();

  // 只有 GPIO0/1/3/5 支持深度睡眠按键唤醒(GPIO10 不支持, 见上面注释),
  // 低电平(按下)唤醒。
  const uint64_t wakePinMask = (1ULL << 0) | (1ULL << 1) | (1ULL << 3) | (1ULL << 5);
  esp_deep_sleep_enable_gpio_wakeup(wakePinMask, ESP_GPIO_WAKEUP_GPIO_LOW);
  esp_sleep_enable_timer_wakeup(DEEP_SLEEP_PERIOD_US);
  gpio_deep_sleep_hold_en();
  esp_deep_sleep_start(); // 不会返回, 芯片断电重启
}

// 当前按下的按键集合(最多 6 个, 跟 HID boot keyboard report 对齐)
uint8_t activeKeys[6] = {0, 0, 0, 0, 0, 0};

void sendKeyboardReport() {
  if (!bleConnected || !pInputKeyboard) {
    return;
  }
  uint8_t report[8] = {0};
  // report[0] = modifier bits (未使用), report[1] = reserved
  memcpy(&report[2], activeKeys, 6);
  pInputKeyboard->setValue(report, sizeof(report));
  pInputKeyboard->notify();
}

void addKey(uint8_t keycode) {
  for (uint8_t i = 0; i < 6; i++) {
    if (activeKeys[i] == keycode) {
      return;  // 已存在
    }
  }
  for (uint8_t i = 0; i < 6; i++) {
    if (activeKeys[i] == 0) {
      activeKeys[i] = keycode;
      break;
    }
  }
  sendKeyboardReport();
}
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
void loop() {
  scanButtons();
  handleUnbondCombo();
  ensureAdvertising();
  goToDeepSleepIfIdle();

  uint32_t now = millis();

  // 开机保护锁到点自动释放(见 bootGraceLock 注释)
  if (bootGraceHeld && (int32_t)(now - bootGraceEndMs) >= 0) {
    esp_pm_lock_release(bootGraceLock);
    bootGraceHeld = false;
  }

  // ---- 闪烁/流水灯的"宏观步进"改成到点才触发一次 applyLedOutputs(),
  //      不再是每次 loop() 都无条件重算一遍。----
  if (ledMode == LED_MODE_BLINK && (int32_t)(now - nextBlinkToggleMs) >= 0) {
    blinkPhaseOn = !blinkPhaseOn;
    nextBlinkToggleMs = now + BLINK_PERIOD_MS / 2;
    applyLedOutputs();
  }
  if (ledMode == LED_MODE_CHASE && (int32_t)(now - nextChaseStepMs) >= 0) {
    chaseIndex = (chaseIndex + 1) % 3;
    nextChaseStepMs = now + CHASE_STEP_MS;
    applyLedOutputs();
  }

  if (now - lastBatteryReportMs >= BATTERY_REPORT_INTERVAL_MS) {
    lastBatteryReportMs = now;
    updateBatteryReading();
  }

  // ---- 省电核心: 不再固定 delay(1), 而是算出"下一件必须要做的事还有多久",
  //      只睡那么久, 用 ulTaskNotifyTake() 代替 delay() —— 这样按键中断可以
  //      随时提前把它叫醒, 没有事件发生时 CPU 能真正进入 light sleep 直到
  //      下一个预定截止时间(最长受限于 ADV_CHECK_INTERVAL_MS=2000ms)。----
  uint32_t nextDeadline = now + ADV_CHECK_INTERVAL_MS; // 兜底上限

  if (bootGraceHeld && (int32_t)(bootGraceEndMs - nextDeadline) < 0) {
    nextDeadline = bootGraceEndMs;
  }

  for (auto &b : buttons) {
    if (b.lastRaw != b.lastStable) {
      uint32_t deadline = b.lastChangeMs + DEBOUNCE_MS;
      if ((int32_t)(deadline - nextDeadline) < 0) nextDeadline = deadline;
    }
  }
  if (ledMode == LED_MODE_BLINK && (int32_t)(nextBlinkToggleMs - nextDeadline) < 0) {
    nextDeadline = nextBlinkToggleMs;
  }
  if (ledMode == LED_MODE_CHASE && (int32_t)(nextChaseStepMs - nextDeadline) < 0) {
    nextDeadline = nextChaseStepMs;
  }
  {
    uint32_t battDeadline = lastBatteryReportMs + BATTERY_REPORT_INTERVAL_MS;
    if ((int32_t)(battDeadline - nextDeadline) < 0) nextDeadline = battDeadline;
  }
  {
    uint32_t advDeadline = lastAdvCheckMs + ADV_CHECK_INTERVAL_MS;
    if ((int32_t)(advDeadline - nextDeadline) < 0) nextDeadline = advDeadline;
  }
  if (comboHolding && !comboTriggered) {
    uint32_t comboDeadline = comboHoldStartMs + UNBOND_HOLD_MS;
    if ((int32_t)(comboDeadline - nextDeadline) < 0) nextDeadline = comboDeadline;
  }

  int32_t sleepMs = (int32_t)(nextDeadline - now);
  if (sleepMs < 1) sleepMs = 1; // 至少让出一次, 避免死循环占满 CPU
  ulTaskNotifyTake(pdTRUE, pdMS_TO_TICKS((uint32_t)sleepMs));
}

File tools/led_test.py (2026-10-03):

#!/usr/bin/env python3
"""
HanHan 5K3L LED 效果测试脚本
----------------------------
通过 BLE 直接写自定义 LED 特征值, 测试三颗 LED 的几种效果模式。

协议(2 字节):
    byte0 = mask, bit0/1/2 分别对应 LED0(GPIO2)/LED1(GPIO6)/LED2(GPIO7) 是否参与显示
    byte1 = mode:
        0 = 全灭 (忽略 mask)
        1 = 常亮 (mask 选中的灯常亮显示, mask=0b111 即"三灯都亮")
        2 = 闪烁 (mask 选中的灯整体慢闪: 亮400ms / 灭400ms)
        3 = 流水灯 (忽略 mask, LED0->LED1->LED2->LED0 顺序点亮, 每步150ms)

    注意: 无论哪种模式, 固件内部都会用 10ms 一帧 / 每颗灯专属 3ms 导通窗口
    的硬件分时复用兜底, 保证任意一颗 LED 的占空比恒定 <=30%。

用法:
    pip install bleak
    python3 led_test.py off
    python3 led_test.py static 0b111        # 三灯都亮
    python3 led_test.py static 0b101        # LED0 和 LED2 亮
    python3 led_test.py blink 0b011         # LED0/LED1 一起慢闪
    python3 led_test.py chase                # 流水灯, mask 参数会被忽略
    python3 led_test.py calib 30 20 30       # 设置 LED0/1/2 分配百分比(每个0~100, 三者总和<=100)

本机(这台开发机)运行此脚本可能会因为没有 GUI/WindowServer 会话导致
CoreBluetooth 权限请求不出来("BLE is not authorized")。如果遇到这种情况,
请把本脚本拷到一台正常有图形界面登录的 Mac 上运行(例如你平时用来测试
HanHan Agent 的那台 Mac), 并在弹出的系统权限提示里允许蓝牙访问。
"""
import asyncio
import sys

from bleak import BleakClient, BleakScanner

DEVICE_NAME = "HanHan 5K3L v0.1"
LED_STATUS_CHAR_UUID = "6e400101-b5a3-f393-e0a9-e50e24dcca9e"
LED_CALIB_CHAR_UUID = "6e400102-b5a3-f393-e0a9-e50e24dcca9e"
ALLOC_SUM_MAX = 100  # 三者总和上限, 单个值理论上也不会超过这个

MODE_OFF = 0
MODE_STATIC = 1
MODE_BLINK = 2
MODE_CHASE = 3


async def find_device(timeout: float = 8.0):
    print(f"[scan] 搜索 '{DEVICE_NAME}' ...")
    device = await BleakScanner.find_device_by_name(DEVICE_NAME, timeout=timeout)
    if device is None:
        print("[scan] 没找到设备, 请确认板子已上电广播、且没有被其他设备连着。")
        sys.exit(1)
    print(f"[scan] 找到: {device.address}")
    return device


async def send(mask: int, mode: int):
    device = await find_device()
    async with BleakClient(device) as client:
        payload = bytes([mask & 0xFF, mode & 0xFF])
        await client.write_gatt_char(LED_STATUS_CHAR_UUID, payload, response=False)
        print(f"[write] mask=0b{mask & 0xFF:08b} mode={mode} -> 已发送")
        await asyncio.sleep(1.0)  # 留点时间让写入真正生效/观察


async def send_calib(percents):
    vals = [max(0, min(ALLOC_SUM_MAX, p)) for p in percents]
    total = sum(vals)
    if total > ALLOC_SUM_MAX and total > 0:
        vals = [v * ALLOC_SUM_MAX // total for v in vals]
    device = await find_device()
    async with BleakClient(device) as client:
        payload = bytes(vals)
        await client.write_gatt_char(LED_CALIB_CHAR_UUID, payload, response=True)
        print(f"[write] 分配比例 LED0/1/2 = {vals} (总和 {sum(vals)}) -> 已发送")
        await asyncio.sleep(1.0)


def parse_mask(arg: str) -> int:
    if arg.lower().startswith("0b"):
        return int(arg, 2)
    return int(arg, 0)


def main():
    if len(sys.argv) < 2:
        print(__doc__)
        sys.exit(1)

    cmd = sys.argv[1].lower()
    if cmd == "off":
        asyncio.run(send(0, MODE_OFF))
    elif cmd == "static":
        mask = parse_mask(sys.argv[2]) if len(sys.argv) > 2 else 0b111
        asyncio.run(send(mask, MODE_STATIC))
    elif cmd == "blink":
        mask = parse_mask(sys.argv[2]) if len(sys.argv) > 2 else 0b111
        asyncio.run(send(mask, MODE_BLINK))
    elif cmd == "chase":
        asyncio.run(send(0b111, MODE_CHASE))
    elif cmd == "calib":
        if len(sys.argv) < 5:
            print("用法: python3 led_test.py calib <led0> <led1> <led2>  (每个 0~100, 总和<=100)")
            sys.exit(1)
        percents = [int(sys.argv[2]), int(sys.argv[3]), int(sys.argv[4])]
        asyncio.run(send_calib(percents))
    else:
        print(f"未知命令: {cmd}")
        print(__doc__)
        sys.exit(1)


if __name__ == "__main__":
    main()

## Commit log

2026-09-30 Initial commit: ESP32-C3 5key3led BLE firmware + HanHan Agent macOS helper
2026-09-30 HanHan Agent: 新增按键动作预设、按 pid 精确锁定目标实例、按键动作设置界面、启动全新实例作为目标功能
    - PresetAction 枚举支持方向键/回车/空格/Tab/Esc/常用组合键等预设
    - 目标应用改为按运行中实例 pid 追踪,解决同一 App 多窗口无法区分的问题
    - 新增菜单: 选择已运行实例 / 打开新实例作为目标 (NSWorkspace createsNewApplicationInstance, 不抢焦点)
    - 新增按键动作设置窗口,可为5个按键分别指定预设动作,设置持久化到 UserDefaults
2026-09-30 chore: 不将打包的 zip 加入版本控制,改用 release 资产分发
2026-09-30 debug: 增加按键拦截/转发流程的 NSLog 日志便于排查无响应问题
2026-09-30 HanHan Agent: 使用憨憨(猫)头像作为 App 图标
    图标来自 gyro-cat-game-ios 仓库的 AppIcon-1024.png, 生成 .icns 并接入 Info.plist/build.sh
2026-09-30 HanHan Agent: 菜单栏图标也换成憨憨头像
2026-10-01 Add 3D printable case design (shell/carrier/back STL + OpenSCAD source)
    Parametric 25mm cube enclosure for the 5-button + 3-LED carrier board
    connected to ESP32-C3-Super-Mini. Includes:
    - shell.stl: main enclosure with front panel button/LED holes + USB-C cutout
    - carrier.stl: pocket plate to hold SMD tactile buttons behind the panel
    - back.stl: screw-on back cover
    - dpad_case.scad: editable OpenSCAD source with all dimensions parametrized
    [back.stl, carrier.stl, dpad_case.scad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]
2026-10-01 Redesign case: enlarge 5-button cross to fill 22x22mm panel, add cap part
    - Cross-pad buttons enlarged and re-centered to use the full available
    panel area (key_pitch 7.5mm, panel hole 6.2mm, up from the cramped
    corner layout)
    - New 'cap' part: oversized button cap with a small rear nub that
    presses the actual tiny SMD switch through the carrier board, so the
    finger target is big while the real tact switch stays tiny
    - LEDs relocated into the empty gaps between the cross arms instead of
    a dedicated top row; hole size relaxed since they only need to glow,
    not be precisely exposed
    - carrier plate enlarged to fill the panel's inner area (22x22 minus
    clearance)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
    [cap.stl, carrier.stl, dpad_case.scad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]
2026-10-01 Move LEDs back to a top row, shrink button caps for clearance
    - 3 LEDs placed as a horizontal row near the panel top instead of
    scattered in cross-arm gaps, so the light is visibly distinct from
    the buttons
    - Button cap/hole size reduced (cap 4.1mm, down from 5.8mm) and the
    cross shifted down (key_cross_cy) to leave verified wall-thickness
    clearance between the up-button hole and the LED row
    - Dimensions re-derived analytically to keep >=0.6mm material between
    adjacent holes and >=1.3mm from panel edges (safe for SLA printing)
    [cap.stl, carrier.stl, dpad_case.scad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]
2026-10-01 dpad_case v4: 按实测贴片按键尺寸重做载板卡槽
    - 新增 button_leg_x/button_body_y/button_h/button_dome_d 等实测参数
    (来自卖家datasheet: 3.3x3.4x1.5mm本体, 引脚左右伸出共4.0mm, 2mm按压圆点)
    - carrier()重写: 左/中/右三键共用一条贯穿宽度的卡槽兼走线槽;
    上/下两键各自独立卡槽+引到右边缘的走线槽
    - carrier_t 提高到2.2mm以容纳1.7mm卡槽深度+0.4mm底板
    - cap的nub_h按零间隙装配关系重算为0.3mm
    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
    [cap.stl, carrier.stl, dpad_case.scad]
2026-10-01 dpad_case v5: 左右按键转90度+独立焊接过线孔, 加大引脚焊接空间
    - 左/右按键朝向整体转90度(引脚变竖直), 让同排的左/中/右三键之间
    从"引脚对引脚"(占4.0mm)变成"本体对本体"(占3.4mm), 腾出空间加大焊接预留
    - leg_margin从约0.15mm提高到0.7mm(单边), perp_margin提高到0.4mm
    - 每个按键的卡槽都改成独立的(不再5键共用一条通槽), 并且在引脚两端各开
    一个独立的过线孔直接贯穿到载板背面, 不同按键的引线完全被实体材料隔开,
    避免焊点/导线互相碰到短路
    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
    [carrier.stl, dpad_case.scad]
2026-10-01 dpad_case v6: 台阶卡槽解决引脚顶住本体问题 + 新增盖板夹紧按键
    根据打样实测反馈重做:
    - 去掉v5的两个过线孔, 卡槽改成'台阶'结构: 中间本体部分挖浅台阶
    (窄边perp_margin从0.4收紧到0.15, 刚好能放进去), 两端引脚区域
    直接挖穿到载板背面(引脚/焊点比本体底面低一截, 之前同一深度会被
    引脚先顶住导致本体扣不到位, 现在挖穿后legs可以自由沉下去,
    这段通槽本身就兼做过线通道)
    - 新增第5个零件 retainer(盖板): 贴在载板背面, 把按键夹在载板和
    盖板之间防止移动, 上面只开小孔(1.0mm)走线对准每个按键两端的
    引脚槽, 靠4个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
    [carrier.stl, dpad_case.scad, retainer.stl]
2026-10-01 v7: simplify carrier pocket to single full-through cut
    - Replace v6's stepped ledge+leg-slot pocket with one simple
    rectangular cut through the full carrier thickness per button.
    This reads as a shallow recess for the button housing from the
    front (per user feedback) while still letting legs/solder/wires
    pass to the back.
    - Removed obsolete stepped-pocket params (ledge_len, ledge_depth,
    pocket_perp_w, leg_slot_len, wire_hole_d/offset) and the now
    redundant actuator_d cutout in carrier() (pocket is already open).
    - Retainer's wire-exit holes repositioned based on simple pocket_len/2.
    - Vertical retention is now purely cap (front) + retainer (back)
    sandwiching the button; carrier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
    [carrier.stl, dpad_case.scad, retainer.stl]
2026-10-01 v8: carrier pocket -> layered blind recess, only dome hole goes through
    Fix second misunderstanding of the carrier pocket design:
    - Pocket is no longer a through-cut rectangle (v7) nor two separate
    deep side slots (v6). It's now ONE recess cut from the carrier's
    BACK face, with two depth layers:
    * leg zone (0.7mm deep, full leg+solder width) - open at the
    back for wires, no cover needed
    * body zone (0.9mm deep, narrow body-only width) - seats the
    button housing snugly
    Only the small actuator hole (for the 2mm dome) continues through
    the remaining ~0.6mm to the front face, so from the front you only
    ever see a small round hole, not a big square cutout.
    - nub_h re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
    [cap.stl, carrier.stl, dpad_case.scad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]
2026-10-01 v9: retainer wire openings -> small holes instead of full leg-zone cutout
    v8 left the retainer fully open over each button's whole leg-zone
    footprint (5.4x3.7mm), which was too big an opening. Revert to two
    small round holes (1.4mm dia) positioned at the two ends of each
    leg zone (where the wires actually exit), keeping the rest of the
    retainer solid so it properly backs/retains the button.
    Verified all 5 parts (shell/carrier/retainer/back/cap) still render
    NoError/manifold; hole positions keep 0.3mm margin from leg-zone
    edges.
    [dpad_case.scad, retainer.stl]
2026-10-02 v10: retainer wire holes -> elongated slots (easier to fit wires)
    Replace the 1.4mm round wire holes with rounded slots
    (retainer_slot_w=1.4 x retainer_slot_len=2.6mm, long axis
    perpendicular to the button's leg direction) so wires have more
    room to pass through each opening. Verified retainer still renders
    NoError/manifold.
    [dpad_case.scad, retainer.stl]
2026-10-02 v11: retainer -> add LED through-holes
    3mm LED body (~4-5mm long) is longer than carrier_t (2.2mm), so a
    chunk of it pokes out the carrier's back into where the retainer
    sits. Without an opening there the retainer would block the LED
    body/leads from continuing through. Added 3 through-holes
    (retainer_led_d = led_hole_d+0.3 = 3.3mm) aligned to the carrier's
    led_dots positions. Verified no collision with corner peg holes and
    retainer still renders NoError/manifold.
    [dpad_case.scad, retainer.stl]
2026-10-03 固件: LED 新增常亮/闪烁/流水灯效果模式, 全部严格遵循 <=30% 占空
    - BLE LED 特征值协议升级为 2 字节(mask + mode), 兼容旧的 1 字节写入(默认常亮)
    - 硬件层统一用 10ms/帧 + 每灯专属 3ms 导通窗口做分时复用, 任意效果模式下
    单颗 LED 占空比恒定 30%, 任意时刻最多一颗导通
    - 新增 tools/led_test.py (bleak) 用于独立测试三种效果
    - 更新 README 说明新协议和测试方法
2026-10-03 HanHan Agent: 新增 LED 控制菜单(CoreBluetooth 直连固件 LED 特征值)
    - HanHanBLEManager 独立管理一条 CoreBluetooth 连接(与 HID 蓝牙键盘配对无关),
    自动扫描名字前缀 'HanHan 5K3L' 的设备, 连上后发现 LED Service/Characteristic
    - 菜单栏新增 'LED 控制' 子菜单: 全灭/三灯都亮/单独点亮某颗/三灯闪烁/流水灯,
    对应预设直接写 2 字节 (mask, mode) 到固件, 和之前 tools/led_test.py 协议一致
    - Info.plist 增加 NSBluetoothAlwaysUsageDescription 蓝牙权限说明
    - build.sh 链接 CoreBluetooth framework
2026-10-03 Fix BLE reconnect bug, add per-LED brightness calibration
    - Firmware: support 2 concurrent BLE connections (HID host + LED control),
    restart advertising on connect (not just disconnect) while slots remain,
    add advertising watchdog in loop() as defensive fallback
    - Firmware: switch LED multiplexing from millis() to micros() for finer
    sub-slot resolution, add ledDutyPercent[3] calibration array + new BLE
    characteristic (0x...102) to tune each LED's on-time within its reserved
    30%-duty slot (compensates for differing LED forward-voltage brightness)
    - Firmware: add Serial debug logging for connect/disconnect/LED writes
    - HanHanAgent: add scan timeout (8s) with user-visible failure stat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
    [esp32c3_5btn_3led_ble.ino, led_test.py]
2026-10-03 HanHanAgent: add global 'follow frontmost window' target mode
    - New TargetMode enum (specificApp / frontmost), persisted via UserDefaults
    - Menu: new top-level '跟随前台窗口(全局)' item, checkmarked like other targets
    - resolveForwardTarget() resolves the live forward pid per keypress: either
    the pinned app instance, or whichever app is currently frontmost
    (excluding HanHanAgent itself, which is LSUIElement so normally never
    becomes frontmost)
    - Selecting a specific running instance or opening a new instance now also
    switches mode back to specificApp
2026-10-03 HanHanAgent: reuse existing system BLE connection for LED control
    Prefer CBCentralManager.retrieveConnectedPeripherals(withServices:) to attach
    to the already-established system Bluetooth connection (the same link used
    for the paired HID keyboard) instead of scanning and opening a second,
    independent BLE connection. Falls back to scanning if no existing connection
    is found (e.g. device not yet paired). Reduces reliance on the firmware's
    concurrent-connection/advertising-watchdog logic and avoids occupying a
    second connection slot.
2026-10-03 Merge LED control + brightness into one window; switch to free 100% budget allocation
    Firmware:
    - Replace fixed 30%-per-LED duty cap with free time-slot allocation: each
    LED gets a slot width = FRAME_US * ledAllocPercent[i] / 100, slots are
    placed back-to-back (non-overlapping) so at most one LED ever conducts at
    once (the real safety property), while the *relative* brightness budget
    (0~100 per LED, sum clamped to <=100 with proportional scale-down) is now
    freely assignable instead of hard-capped at 30% each
    - clampLedAllocation() helper mirrors this clamping logic for BLE writes
    - Updated top-of-file doc comment to describe the new allocation model
    HanHanAgent:
    - Replaced the sep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
    [esp32c3_5btn_3led_ble.ino, led_test.py]
2026-10-04 Add battery voltage monitoring + power-saving optimizations
    - Battery: GPIO4 ADC1 divider sensing (16-sample avg), piecewise
    LiPo discharge curve, standard BLE Battery Service + custom
    voltage/percent characteristic (6E400103-...), 10s report interval.
    Moved F16 button from GPIO4 to GPIO5 (ADC2/GPIO5 unusable for ADC
    on ESP32-C3, GPIO5 still fine as digital input).
    - Power saving: reduce CPU to 80MHz, request longer BLE connection
    interval + slave latency on connect, yield 1ms per loop() iteration
    so the FreeRTOS idle task can run (previous loop was a tight busy
    spin that never idled). Documented that full automatic light-sleep/
    BLE modem-sleep requires a custom ESP-IDF build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
    [esp32c3_5btn_3led_ble.ino]
2026-10-04 迁移固件到 ESP-IDF 工程并大幅优化 BLE 待机功耗
    从 Arduino IDE 迁移到自定义 ESP-IDF v5.5 工程(使用 arduino-esp32 作为
    ESP-IDF 组件), 目的是解锁 Arduino 预编译核心不具备的电源管理能力
    (CONFIG_PM_ENABLE / CONFIG_BT_CTRL_MODEM_SLEEP / light sleep)。
    主要修复与优化:
    - 修复 BLE 控制器初始化崩溃: 覆盖 bleInUse() 弱符号, 避免 Arduino
    initArduino() 误判 BLE 未使用而提前释放 BLE 控制器内存。
    - 开启 CONFIG_BT_CTRL_MAIN_XTAL_PU_DURING_LIGHT_SLEEP, 解决 BLE 开启
    后 light sleep 被完全禁用的问题(待机功耗 0.24W -> 0.07-0.1W)。
    - LED 驱动从 CPU 每 1ms 轮询的软件时分复用改为硬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
    [main.cpp]
2026-10-04 firmware: 降低BLE发射功率到-3dBm + 增加连接参数诊断日志
    - NimBLEDevice::setPower(-3): 默认最大功率对桌面距离的使用场景是浪费,
    调低可以省下每次广播/连接事件的射频峰值电流。先试了-9dBm, 发现桌面
    正常距离下信号不够稳定(需要贴近才能扫到/保持连接), 没有在-9dBm下
    测出功耗数据就直接放弃了这个档位; 回调到-3dBm后蓝牙识别连接正常。
    - 新增 onConnParamsUpdate 回调, 打印对端实际采纳的连接间隔/延迟/超时,
    用于诊断"macOS系统蓝牙HID策略强制短连接间隔"这个假设(连接态下日志
    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
2026-10-04 firmware: 连上设备后停止继续广播, 大幅降低连接态功耗
    MAX_DESIRED_CONNECTIONS 从 2 改成 1。原来设成2是以为手机/电脑的HID连接
    和HanHan Agent的LED控制连接需要各占一条独立连接, 所以连上一个设备后还
    继续广播等第二个设备来连。后来证实HanHan Agent会优先复用系统已有连接
    (retrieveConnectedPeripherals), 并不会额外建连接; 用户确认平时也只用
    一台设备连接, 所以继续广播是纯浪费——广播本身需要周期性发包, 即使已经
    有一条连接在占用, 这部分射频开销仍然持续存在。
    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
2026-10-04 firmware: 电池电压检测间隔 10秒->60秒
    电池电压变化很慢, 不需要10秒级的采样频率, 拉长到60秒减少ADC采样唤醒次数。
    本轮还试过把 CPU max_freq 从80MHz降到40MHz, 但实测会导致btController任务
    饿死IDLE任务, 触发watchdog反复复位崩溃, 已确认不可行并撤销, 保持80MHz。
    也尝试过抓取onConnParamsUpdate诊断日志来确认实际BLE连接间隔, 但受限于
    USB-Serial-JTAG在light sleep后不可用+软复位不稳定, 多次尝试都未能可靠
    捕获到日志, 放弃这个诊断方向(和之前架构调试阶段的结论一致)。
2026-10-04 固件: 深度睡眠空闲架构 + 修复重连/绑定丢失问题
    背景: 常连接架构功耗始终压不到 0.1W 以下(40mAh 电池实测只能撑 ~2 小时),
    改为深度睡眠架构: 空闲时整机断电睡眠, 定时醒来广播 + 支持按键唤醒,
    平均功耗从 0.12-0.16W 降到约 0.03W。
    本次修复的两个严重 bug(此前深睡眠架构在真实测试中完全不可用):
    1. 绑定信息随睡眠丢失(根因): 深度睡眠 = 完整重启, NimBLE 默认把配对/
    绑定信息只存 RAM, 每次睡眠都会清空, 但电脑还记得旧绑定, 造成连接失败
    /每次弹确认框("Peer removed pairing information")。开启
    CONFIG_BT_NIMBLE_NVS_PERSIST, 绑定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
    [main.cpp]
2026-10-04 Agent: LED 效果连接后自动补发, 确认写入成功才清理待发状态
    之前的 pendingPayload 只在"调用 send() 时还没连上"才会记录, 且在重连后
    立刻 send() 就清空, 没有真正等固件确认写入成功, 也没有覆盖"已经连着但
    固件突然断连(比如进入深度睡眠)"的场景。
    现在改为:
    - send() 无论当前是否已连接, 都先记下"用户最近一次想要的 LED 效果"。
    - 只有收到 CBPeripheralDelegate.didWriteValueFor 对 LED 特征值的无错误
    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
